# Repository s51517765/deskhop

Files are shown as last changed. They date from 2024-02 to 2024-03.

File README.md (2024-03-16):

# DeskHop - Fast Desktop Switching

## 概要 (Overview)

このプロジェクトは https://github.com/hrvach/deskhop のForkです。

[Original README.md](README_original.md)

以下はオリジナルより引用。

テクノロジーのクレイジーな世界では、競合相手が左利き用ドライバーと自動的に隠れる目覚まし時計だけかもしれないほどニッチな問題を解決しようとする、風変わりな小さなプロジェクトが常に存在することに気づいたことがありますか?

私は毎日のワークフローで 2 台の異なるコンピューターを使用しており、それらの間で 1 つのキーボードとマウスのペアを共有しています。 Amazon で見つけたいくつかの USB スイッチング ボックスを試してみたところ、どれも同様の問題を抱えていることがわかりました。切り替えには時間がかかり、ボタンを探すときのプロセスは非常にぎこちなく、率直に言って、時間が経っても改善されません。

私が欲しかったのは、キーボード ショートカットを使用して出力をすばやく切り替える方法と、マウス ポインタを魔法のようにモニタ間で移動することで同じことを行う機能です。 このプロジェクトを使用すると、コンピュータで異なるオペレーティング システムが実行されている場合でも、両方を行うことができます。

## オリジナルとの差分（Differences from Original）

タクトスイッチ（Board B）にPC Bのマウス速度を切り替える機能を追加

## 動画 (Movie)

https://twitter.com/s51517765/status/1760995792129872011

## 実装イメージ (Pictures)

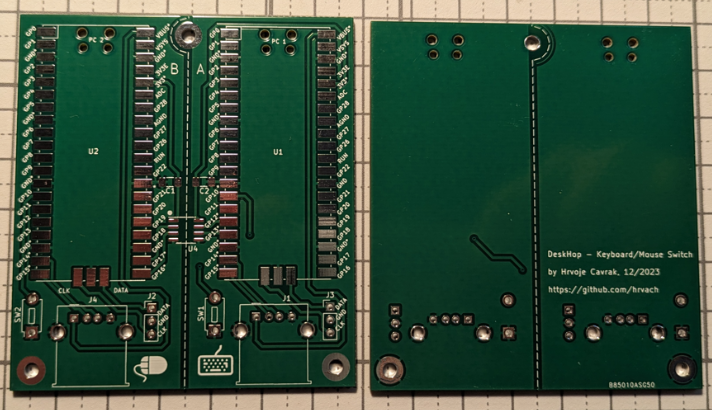
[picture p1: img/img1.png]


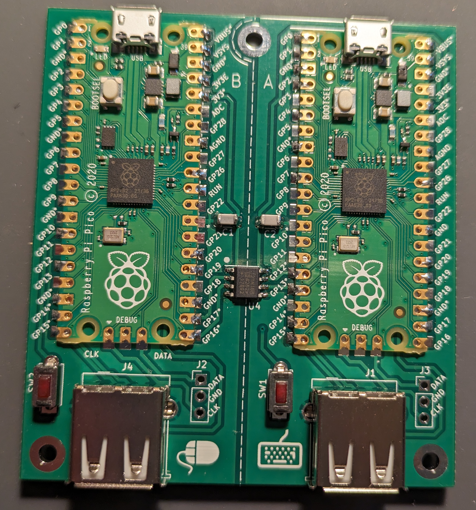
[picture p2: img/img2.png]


オリジナルに対して、タクトスイッチを2つ追加している。

## 動作要件 (Requirements)

RaspberryPi Pico / C++

## 部品リスト (Parts List)

|部品|種類|数量|秋月コード|価格|
| --- | --- |--- |--- |--- |
|基板取付用USBコネクタ|Aタイプ メス|2個|115180|50*2|
|タクトスイッチ|TVBP06-B043CR-B|2個【オプション】|108213|20*2|
|デジタルアイソレーター|ADuM121N1BRZ|1個|113619|320|
|チップ積層セラミックコンデンサー|0.1μF100V C0G 3216|1パック5個入|115180|120|
|Raspberry Pi Pico|-|2個|116132|770*2|
|USB Type B microケーブル|-|2個|-|-|

部品についてはオリジナルの部品リストから、同等のものを秋月電子のラインナップから選定した。USB Type B microケーブルについては一般的なものが使用できるはずである。

## ライセンス (License)
 GNU GENERAL PUBLIC LICENSE Version 3, 29 June 2007

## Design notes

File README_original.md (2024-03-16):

#  DeskHop - Fast Desktop Switching

Did you ever notice how, in the crazy world of tech, there's always that one quirky little project trying to solve a problem so niche that its only competitors might be a left-handed screwdriver and a self-hiding alarm clock?

I use two different computers in my daily workflow and share a single keyboard/mouse pair between them. Trying several USB switching boxes found on Amazon made me realize they all suffer from similar issues - it takes a while to switch, the process is quite clumsy when trying to find the button and frankly, it just doesn't get any better with time. 

All I wanted was a way to use a keyboard shortcut to quickly switch outputs, paired with the ability to do the same by magically moving the mouse pointer between monitors. This project enables you to do both, even if your computers run different operating systems!



## Features

- Completely **free and open source**
- No noticeable delay when switching
- Simply drag the mouse pointer between computers
- No software installed
- Affordable and obtainable components (<15€)
- 3D printable snap-fit case
- Full Galvanic isolation between your outputs
- Works with Linux, macOS and Windows

------

## How it works

The device acts as an intermediary between your keyboard/mouse and the computer, establishing and maintaining connections with both computers at once. Then it chooses where to forward your mouse and keystrokes to, depending on your selection. Keyboard follows the mouse and vice versa, so just dragging the mouse to the other desktop will switch both.

## Mouse 

To get the mouse cursor to magically jump across, the mouse hid report descriptor was changed to use absolute coordinates and then the mouse reports (that still come in relative movements) accumulate internally, keeping the accurate tally on the position. 

When you try to leave the monitor area in the direction of the other monitor, it keeps the Y coordinate and swaps the maximum X for a minimum X, then flips the outputs. This ensures that the cursor seamlessly appears at the same height on the other monitor, enhancing the perception of a smooth transition.



 <p align="center"> Dragging the mouse from Mac to Linux automatically switches outputs. 
 </p>

-----
 
The actual switch happens at the very moment when one arrow stops moving and the other one starts.

## Keyboard

Acting as a USB Host and querying your keyboard periodically, it looks for a preconfigured hotkey in the hid report (usually Caps Lock for me). When found, it will forward all subsequent characters to the other output.

To have a visual indication which output you are using at any given moment, you can repurpose keyboard LEDs and have them provide the necessary feedback. 

It also remembers the LED state for each computer, so you can pick up exactly how you left it. 



## How to build

```
PICO_BOARD=pico PICO_SDK_PATH=/your/sdk/path cmake -S . -B build
cmake --build build
```

## Using pre-built images

Alternatively, you can use the [pre-built images](binaries/). Take the Pico board that goes to slot A on the PCB and hold the on-board button while connecting the cable.

It should appear as a USB drive on your system. Copy the corresponding board_A.uf2 file there and repeat the same with B.

## Upgrading firmware

Option 1 - Open the case, hold the button while connecting each Pico and copy the right uf2 to it.

Option 2 - Switch a board to BOOTSEL mode by using a special key combination (listed below). 

This will make the corresponding Pico board enter the bootloader upgrade mode and act as USB flash drive. Now you can drag-and-drop the .uf2 file to it (you might need to plug in your mouse directly).

## Misc features

### Mouse slowdown

Ever tried to move that YT video slider to a specific position but your mouse moves too jumpy and suddenly you are moving your hand super-carefully like you're 5 and playing "Operation" all over again?

**Press right CTRL + right ALT** to toggle a slow-mouse mode. The mouse pointer will slow down considerably, enabling you to get the finer precision work done and still have your mouse moving normally by quickly pressing the same keys again.

### Switch Lock

If you want to lock yourself to one screen, use ```RIGHT CTRL + L```.
This will make sure you won't accidentally leave your current screen. To turn off, press the same key combo again.

### Screensaver

Supposedly built in to prevent computer from entering standby, but truth be told - it is just fun to watch. Off by default, will make your mouse pointer bounce around the screen like a Pong ball. When enabled, it activates after a period of inactivity defined in user config header and automatically switches off as soon as you send any output towards that screen. 



## Hardware

[The circuit](schematics/DeskHop.pdf) is based on two Raspberry Pi Pico boards, chosen because they are cheap (4.10 € / pc), can be hand soldered and most suppliers have them in stock.

The Picos are connected using UART and separated by an Analog Devices ADuM1201 dual-channel digital isolator (~3€). 

While they normally don't have support for dual USB, thanks to an [amazing project](https://github.com/sekigon-gonnoc/Pico-PIO-USB) where USB is implemented using the programmable IO wizardry found in RP2040, there is support for it to act both as an USB host and device.  

## PCB

To keep things as simple as possible for DIY builds, the traces were kept on one side and the number of parts kept to a theoretical minimum.



USB D+/D- differential lines should be identical in length, but they are slightly asymmetrical on purpose to counter the length difference on the corresponding GPIO traces PICO PCB itself, so the overall lengths should match.

Zd (differential impedance) is aimed as 90 ohm (managed to get ~107, close enough :)).

The thickness is designed to be 1.6 mm for snap-fit to work as expected.

Planned changes:
- Add 15 ohm resistors for D+ / D- lines
- Add decoupling capacitance near VBUS line on USB-A connector (~100 uF)
- Add an ESD protection device near the USB connector
- Add indications on the silkscreen for pin1 on the ADuM1201
- Add indications on the silkscreen for which Raspberry Pi Pico pins need to be soldered

## Case

Since I'm not very good with 3d, the case is [simple and basic](case/) but does the job. It should be easy to print, uses ~33g of filament and takes a couple of hours.

Horizontal PCB movements are countered by pegs sliding through holes and vertical movements by snap-fit lugs on the side - no screws required.

Micro USB connectors on both boards are offset from the side of the case, so slightly larger holes should allow for cables to reach in. 

The lid is of a snap-fit design, with a screwdriver slot for opening. The markings on top are recessed and can be finished with e.g. crayons to give better contrast (or simply left as-is).



## Bill of materials

| Component | Qty | Unit Price / € | Price / €|
|---|-----|---|---|
| Raspberry Pi Pico  | 2 | 4.10 | 8.20 |
| ADuM1201BRZ | 1 | 2.59 | 2.59 |
| Cap 1206 SMD 100nF | 2 | 0.09 | 0.18 |
| USB-A PCB conn. | 2 | 0.20 | 0.40 |
| Headers 2.54 1x03  | 2 | 0.08 | 0.16 |
| | | | |
| | | Total | 11.53 |

USB-A connector can be Molex MX-67643-0910 or a cheaper/budget one that shares the same dimensions.

Additional steps:

 - making the PCB ([Gerber provided](pcb/), choose 1.6 mm thickness)
 - 3d printing the case ([stl files provided](case/), ~33g filament)

## Assembly guide

If you have some experience with electronics, you don't need this. However, some of you might not, and in that case this video might help guide you through the process. Please note, after soldering you should clean the flux from the PCB to prevent corrosion. 

The standard process to do that is using isopropyl alcohol and an old toothbrush. But guess what? I'm not putting my old toothbrush online, so you'll just have to improvise that part :)

PCB Assembly Guide (https://www.youtube.com/watch?v=LxI9NYi_oOU)

## Usage guide

### Keyboard shortcuts

_Firmware upgrade_
- ```Right Shift + F12 + Left Shift + A``` - put board A in FW upgrade mode
- ```Right Shift + F12 + Left Shift + B``` - put board B in FW upgrade mode

_Usage_
- ```Right CTRL + Right ALT``` - Toggle slower mouse mode
- ```Right CTRL + L``` - Lock/Unlock mouse desktop switching
- ```Caps Lock``` - Switch between outputs

_Config_
- ```Right Shift + F12 + D``` - remove flash config
- ```Right Shift + F12 + Y``` - save screen switch offset
- ```Right Shift + F12 + S``` - turn on/off screensaver option

### Switch cursor height calibration

This step is not required, but it can be handy if your screens are not perfectly aligned or differ in size. The objective is to have the mouse pointer come out at exactly the same height.



Just park your mouse on the LARGER screen at the height of the smaller/lower screen (illustrated) and press ```Right Shift + F12 + Y```. Your LED (and caps lock) should flash in confirmation.

Repeat for the bottom border (if it's above the larger screen's border). This will get saved to flash and it should keep this calibration value from now on.

### Other configuration

Mouse speed can now be configured per output screen and per axis. If you have multiple displays under Linux, your X speed is probably too fast, so you need to configure it in user_config.h and rebuild. In the future, this will be configurable without having to do that.

### Functional verification

When you connect a new USB peripheral, the board will flash the led twice, and instruct the other board to do the same. This way you can test if USB and outgoing communication works for each board.

Do this test by first plugging the keyboard on one side and then on the other. If everything is OK, leds will flash quickly back and forth in both cases.

## FAQ

1. I just have two Picos, can I do without a PCB and isolator?

*Sure. Having an isolator is recommended but it should work without it.*

2. What happens if I have two different resolutions on my monitors?

*The mouse movement is done in abstract coordinate space and your computer figures out how that corresponds with the physical screen, so it should just work.*

3. Where can I buy it?

*I'm not selling anything, this is just a personal, non-commercial hobby project.*

*[update] There is a manufacturing/assembly company in China that might offer PCBs in qty of 1, assembled boards and boards + case, so stay tuned.*

*I **don't want to take any commission** on this - the only goal is to provide an alternative for people who don't feel confident enough to assemble the boards themselves.*

4. When the active screen is changed via the mouse, does the keyboard follow (and vice versa)?

*Yes, the idea was to make it behave like it was one single computer.*

5. Will this work with keyboard/mouse combo dongles, like the Logitech Unifying receiver?

*Not tested yet, but the latest version might actually work (please provide feedback).*

6. Will this work with wireless mice and keyboards that have separate wireless receivers (one for the mouse, another for the keyboard)?

*It should work - tried an Anker wireless mouse with a separate receiver and that worked just fine.*

7. I have issues with build or compilation

*Check out the [Troubleshooting Wiki](https://github.com/hrvach/deskhop/wiki/Troubleshooting) that might have some answers.*

## Software Alternatives

There are several software alternatives you can use if that works in your particular situation.

1. [Barrier](https://github.com/debauchee/barrier) - Free, Open Source
2. [Input Leap](https://github.com/input-leap/input-leap) - Free, Open Source
3. [Synergy](https://symless.com/synergy) - Commercial
4. [Mouse Without Borders](https://www.microsoft.com/en-us/garage/wall-of-fame/mouse-without-borders/) - Free, Windows only
5. [Universal Control](https://support.apple.com/en-my/HT212757) - Free, Apple thing

## Shortcomings

- Windows 10 broke HID absolute coordinates behavior in KB5003637, so you can't use more than 1 screen on Windows (mouse will stay on the main screen).
- Code needs cleanup, some refactoring etc.
- Occasional bugs and weird behavior.
- Not tested with a wide variety of devices, I don't know how it will work with your hardware. There is a reasonable chance things might not work out-of-the-box. 
- Advanced keyboards (with knobs, extra buttons or sliders) will probably face issues where this additional hardware doesn't work.
- Super-modern mice with 300 buttons might see some buttons not work as expected.
- NOTE: Both computers need to be connected and provide power to the USB for this to work (as each board gets powered by the computer it plugs into). Many desktops and laptops will provide power even when shut down nowadays. If you need to run with one board fully disconnected, you should be able to use a USB hub to plug both keyboard and mouse to a single port.

## Progress

So, what's the deal with all the enthusiasm? I can't believe it - please allow me to thank you all! I've never expected this kind of interest in a simple personal project, so the initial features are pretty basic (just like my cooking skills) and mostly cover my own usecase. Stay tuned for firmware updates that should bring wider device compatibility, more features and less bugs. As this is a hobby project, I appreciate your understanding for being time-constrained and promise to do the best I can.

Planned features:
- ~~Proper TinyUSB host integration~~ (done)
- ~~HID report protocol parsing, not just boot protocol~~ (mostly done)
- ~~Support for unified dongle receivers~~
- ~~Support for USB hubs and single-sided operation~~
- Configurable screens (partially)
- ~~Permament configuration stored in flash~~
- Better support for keyboards with knobs and mice with mickeys
- Unified firmware for both Picos
- ... and more!

Mouse polling should now work at 1000 Hz (the dips in the graph is my arm hurting from all the movement :-)):

Mouse polling rate

## Disclaimer

I kindly request that anyone attempting to build this project understands and acknowledges that I am not liable for any injuries, damages, or other consequences. Your safety is important, and I encourage you to approach this project carefully, taking necessary precautions and assuming personal responsibility for your well-being throughout the process. Please don't get electrocuted, burned, stressed or angry. Have fun and enjoy! 

Happy switchin'!

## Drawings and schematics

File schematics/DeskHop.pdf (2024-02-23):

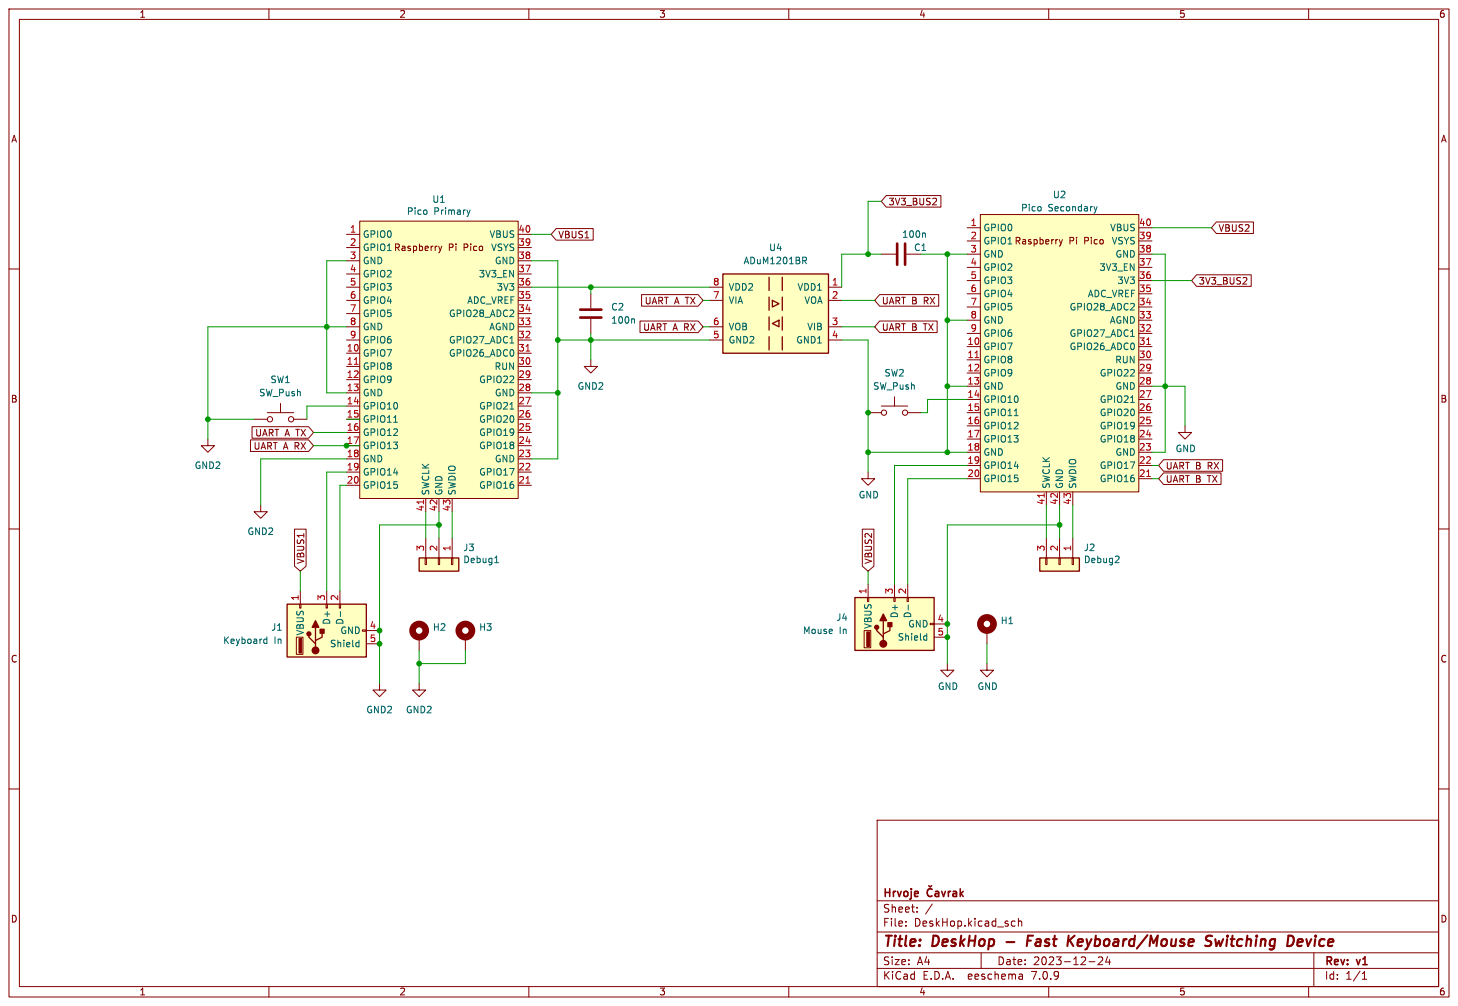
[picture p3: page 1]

3V3_BUS2 UART A TX UART A RX

File: DeskHop.kicad_sch Sheet: / Hrvoje þÿavrak

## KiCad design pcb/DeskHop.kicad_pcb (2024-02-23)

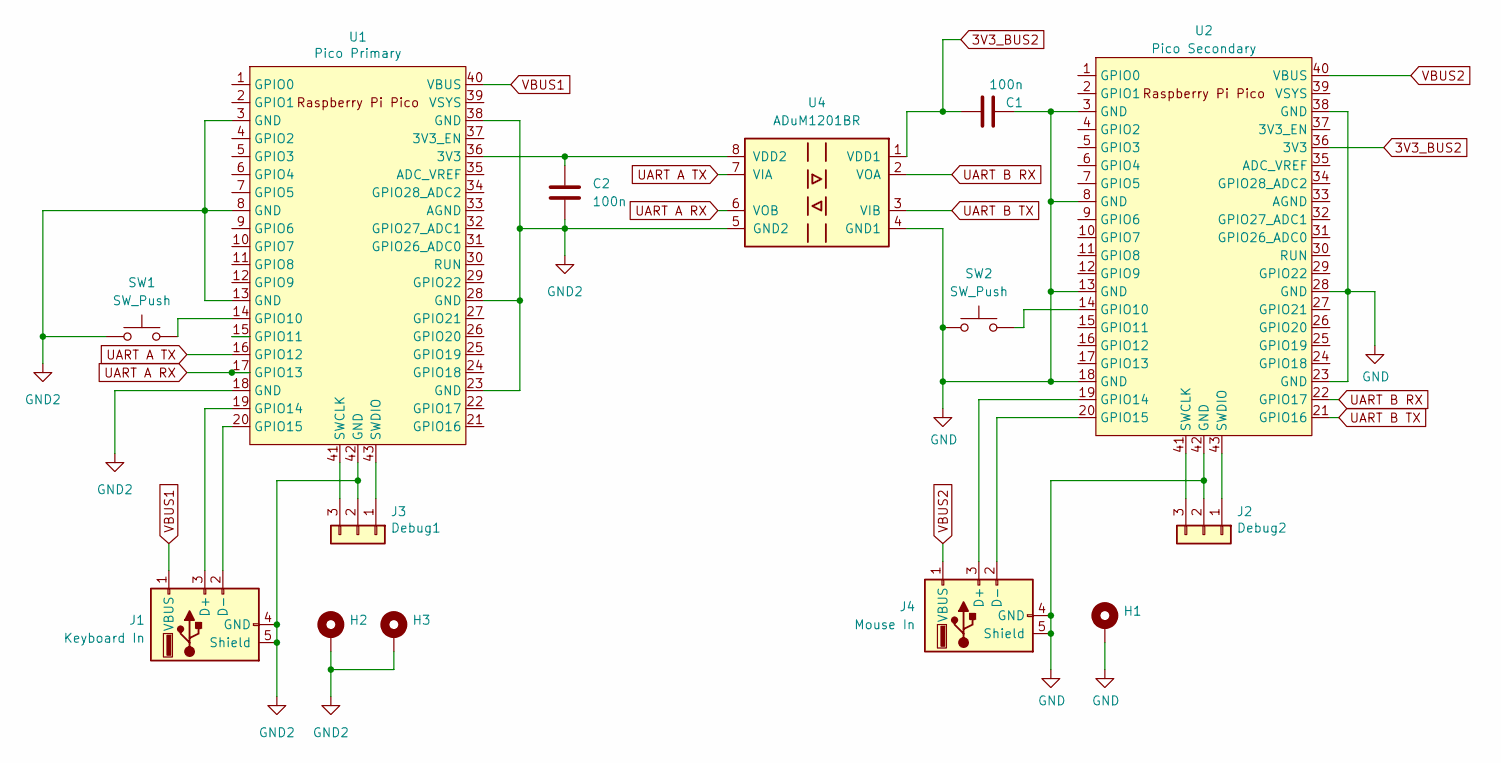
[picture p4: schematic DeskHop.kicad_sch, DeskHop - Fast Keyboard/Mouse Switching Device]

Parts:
C1, C2: 100n; C_1206_3216Metric_Pad1.33x1.80mm_HandSolder
H1, H2: MountingHole_Pad; MountingHole_2.7mm_M2.5_Pad_TopBottom
H3: MountingHole_Pad; MountingHole_2.7mm_M2.5_Pad_TopOnly
J1: Keyboard In; USB_A_Molex_67643_Horizontal
J2: Debug2; PinHeader_1x03_P2.54mm_Vertical
J3: Debug1; PinHeader_1x03_P2.54mm_Vertical
J4: Mouse In; USB_A_Molex_67643_Horizontal
SW1, SW2: SW_Push; SW_PUSH_1P1T_6x3.5mm_H5.0_APEM_MJTP1250
U1: Pico Primary; RPi_Pico_SMD_Nohole
U2: Pico Secondary; RPi_Pico_SMD_Nohole
U4: ADuM1201BR; SOIC-8_3.9x4.9mm_P1.27mm

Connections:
3V3_BUS2: C1.1, U2.36 (3V3), U4.1 (VDD1)
GND: C1.2, H1.1, J2.2, J4.4 (GND), J4.5 (Shield), SW2.1, U2.3 (GND), U2.8 (GND), U2.13 (GND), U2.18 (GND), U2.23 (GND), U2.28 (GND), U2.38 (GND), U2.42 (GND), U4.4 (GND1)
GND2: C2.2, H2.1, H3.1, J1.4 (GND), J1.5 (Shield), J3.2, SW1.1, U1.3 (GND), U1.8 (GND), U1.13 (GND), U1.18 (GND), U1.23 (GND), U1.28 (GND), U1.38 (GND), U1.42 (GND), U4.5 (GND2)
unnamed: J1.3 (D+), U1.19 (GPIO14)
unnamed: J1.2 (D-), U1.20 (GPIO15)
unnamed: J2.1, U2.43 (SWDIO)
unnamed: J2.3, U2.41 (SWCLK)
unnamed: J3.1, U1.43 (SWDIO)
unnamed: J3.3, U1.41 (SWCLK)
unnamed: J4.3 (D+), U2.19 (GPIO14)
unnamed: J4.2 (D-), U2.20 (GPIO15)
unnamed: C2.1, U1.36 (3V3), U4.8 (VDD2)
unnamed: SW1.2, U1.14 (GPIO10)
unnamed: SW2.2, U2.14 (GPIO10)
UART A RX: U1.17 (GPIO13), U4.6 (VOB)
UART A TX: U1.16 (GPIO12), U4.7 (VIA)
UART B RX: U2.22 (GPIO17), U4.2 (VOA)
UART B TX: U2.21 (GPIO16), U4.3 (VIB)
VBUS1: J1.1 (VBUS), U1.40 (VBUS)
VBUS2: J4.1 (VBUS), U2.40 (VBUS)

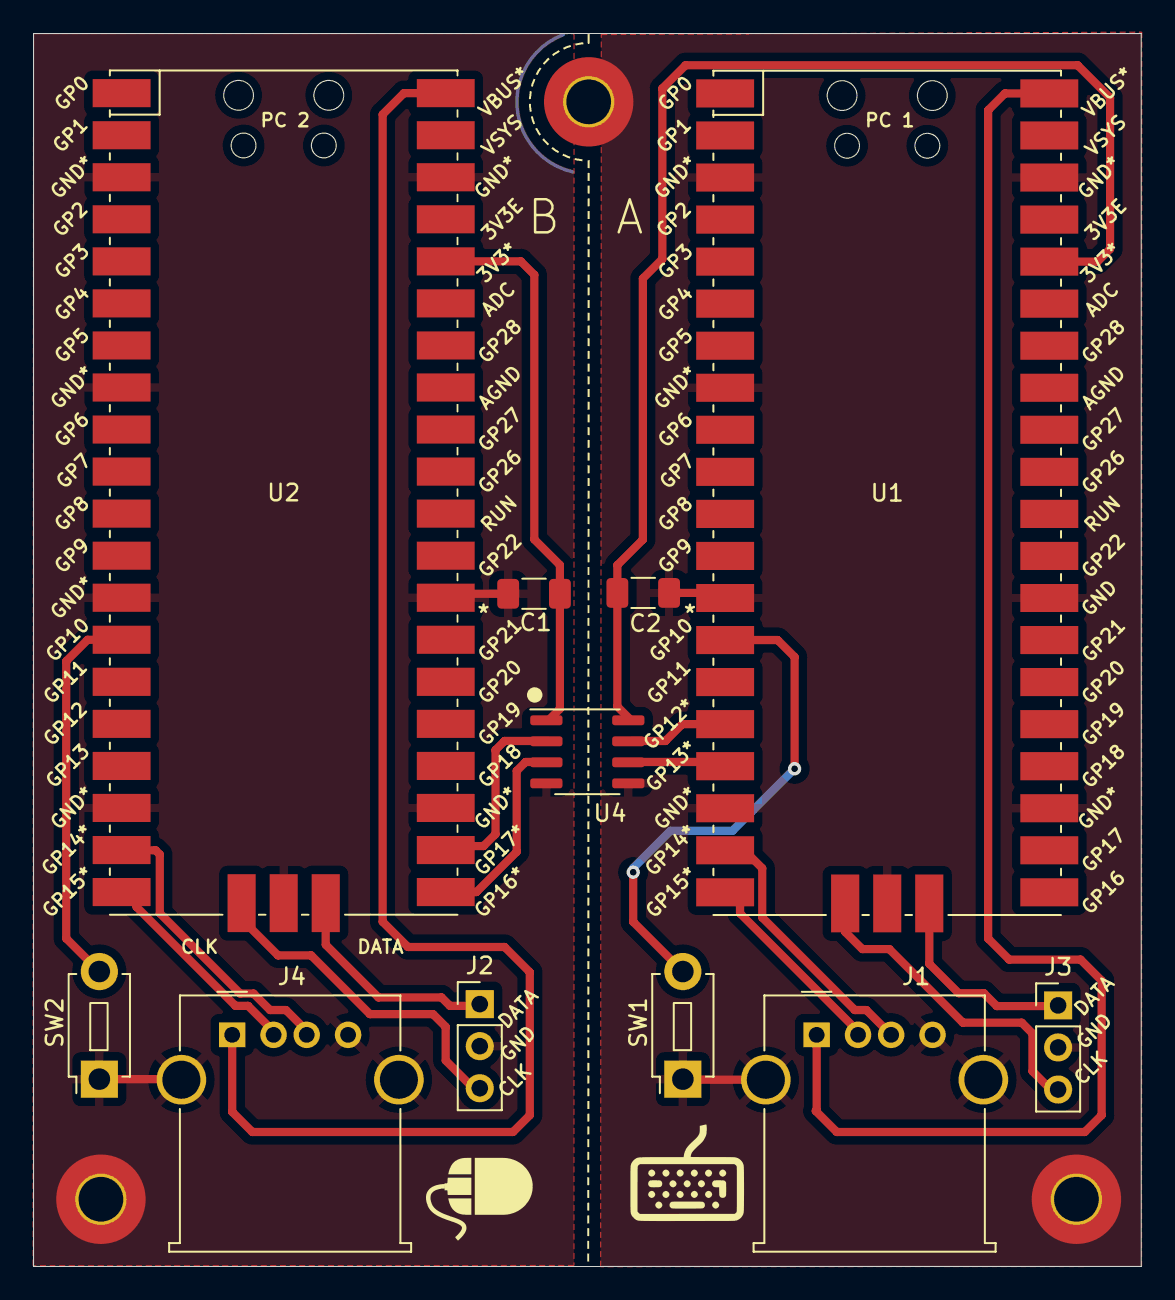
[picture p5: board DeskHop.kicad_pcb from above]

Board: 2 copper layers, 66.9 x 74.5 mm, 14 parts (0 on the bottom side), 20 nets.

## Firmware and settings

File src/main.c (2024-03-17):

/*
 * This file is part of DeskHop (https://github.com/hrvach/deskhop).
 * Copyright (c) 2024 Hrvoje Cavrak
 *
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
 * You should have received a copy of the GNU General Public License
 * along with this program. If not, see <http://www.gnu.org/licenses/>.
 */

#include "main.h"
#include "switch.h"
/*********  Global Variable  **********/
device_t global_state = {0};
device_t *device      = &global_state;

/**================================================== *
 * ==============  Main Program Loops  ============== *
 * ================================================== */

int main(void) {
    // Wait for the board to settle
    sleep_ms(10);

    // Initial board setup
    initial_setup(device);

    // Initial state, A is the default output
    switch_output(device, OUTPUT_A);

    init_push_swicth();

    while (true) {
        // USB device task, needs to run as often as possible
        tud_task();

        // Verify core1 is still running and if so, reset watchdog timer
        kick_watchdog(device);

        // Check if there were any keypresses and send them
        process_kbd_queue_task(device);

        // Check if there were any mouse movements and send them
        process_mouse_queue_task(device);

        if (read_SW(PIN_SW)) {
            update_mouse_speed(device);
        }
    }
}

void core1_main() {
    uart_packet_t in_packet = {0};

    while (true) {
        // Update the timestamp, so core0 can figure out if we're dead
        device->core1_last_loop_pass = time_us_64();

        // USB host task, needs to run as often as possible
        if (tuh_inited())
            tuh_task();

        // Receives data over serial from the other board
        receive_char(&in_packet, device);

        // Check if LED needs blinking
        led_blinking_task(device);

        // Mouse screensaver task
        screensaver_task(device);
    }
}

/* =======  End of Main Program Loops  ======= */

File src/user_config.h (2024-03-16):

/**===================================================== *
 * ==========  Keyboard LED Output Indicator  ========== *
 * ===================================================== *
 *
 * If you are willing to give up on using the keyboard LEDs for their original purpose,
 * you can use them as a convenient way to indicate which output is selected.
 *
 * KBD_LED_AS_INDICATOR set to 0 will use the keyboard LEDs as normal.
 * KBD_LED_AS_INDICATOR set to 1 will use the Caps Lock LED as indicator.
 *
 * */

#define KBD_LED_AS_INDICATOR 0

/**===================================================== *
 * ===========  Hotkey for output switching  =========== *
 * ===================================================== *
 *
 * Everyone is different, I prefer to use caps lock because I HATE SHOUTING :)
 * You might prefer something else. Pick something from the list found at:
 *
 * https://github.com/hathach/tinyusb/blob/master/src/class/hid/hid.h
 *
 * defined as HID_KEY_<something>
 *
 * */

#define HOTKEY_TOGGLE HID_KEY_CAPS_LOCK

/**================================================== *
 * ==============  Mouse Speed Factor  ============== *
 * ==================================================
 *
 * This affects how fast the mouse moves.
 *
 * MOUSE_SPEED_A_FACTOR_X: [1-128], mouse moves at this speed in X direction
 * MOUSE_SPEED_A_FACTOR_Y: [1-128], mouse moves at this speed in Y direction
 *
 * JUMP_THRESHOLD: [0-32768], sets the "force" you need to use to drag the
 * mouse to another screen, 0 meaning no force needed at all, and ~500 some force
 * needed, ~1000 no accidental jumps, you need to really mean it.
 *
 * This is now configurable per-screen.
 *
 * */

/* Output A values */
#define MOUSE_SPEED_A_FACTOR_X 64
#define MOUSE_SPEED_A_FACTOR_Y 88 //88

/* Output B values */
#define MOUSE_SPEED_B_FACTOR_X 24 // Linux
#define MOUSE_SPEED_B_FACTOR_Y 80 // Linux

#define JUMP_THRESHOLD 0

/**================================================== *
 * ==============  Screensaver Config  ============== *
 * ==================================================
 *
 * Defines how long does an output need to be idle for screensaver to kick in.
 * With this function, after being left idle for a certain amount of time (defined below),
 * mouse cursor starts moving around like a bouncy-ball in pong. No clicking, of course.
 * Move mouse on that active output to stop.
 *
 * SCREENSAVER_ENABLED: [0 or 1] 0 means screensaver is disabled, 1 means it is enabled.
 * SCREENSAVER_TIME_SEC: time in seconds
 *
 * */

#define SCREENSAVER_ENABLED  0
#define SCREENSAVER_TIME_SEC 240

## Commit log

2024-02-23 Add switch to PCB board
    [DeskHop-B_Cu.gbr, DeskHop-B_Mask.gbr, DeskHop-B_Paste.gbr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]
2024-02-23 Add schematics.pdf
2024-03-16 Add switch-B function
2024-03-16 誤記訂正

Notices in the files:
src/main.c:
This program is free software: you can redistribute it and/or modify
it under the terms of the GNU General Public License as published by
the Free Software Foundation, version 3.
